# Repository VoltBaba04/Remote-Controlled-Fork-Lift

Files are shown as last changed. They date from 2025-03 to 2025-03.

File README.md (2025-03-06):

Remote-Controlled Forklift with Video Streaming

**Project Overview :** 
This project is a remote-controlled forklift system designed for industrial use, controlled using Arduino Nano with live video streaming via ESP32-CAM. The forklift is controlled remotely using two joysticks: one for 4WD vehicle movement and the other for forklift lift and angle control. The project uses NRF24L01 wireless modules for long-range communication between the transmitter and receiver. The ESP32-CAM module streams live video, allowing real-time monitoring of the forklift’s environment.

**System Architecture :** 
The system is divided into two main sections: the transmitter and the receiver.

**Transmitter:**
Arduino Nano: 
Processes inputs from joysticks.

**NRF24L01:**
Transmits the joystick control signals wirelessly.

**Two Joysticks:**
Joystick 1: Controls vehicle movement (forward, reverse, left, right).
Joystick 2: Controls forklift lifting and fork angle.

**Power Supply:**
Powered by USB or a regulated 5V power source.

**Receiver:**
Arduino Nano:
Receives commands and controls the motors.

**NRF24L01:**
Receives wireless signals from the transmitter.

**L298N Motor Drivers (2):**
One motor driver controls 4WD motors for vehicle movement.
The other motor driver controls the forklift lifting motor.

**ESP32-CAM:**
Streams live video for real-time monitoring of the forklift's surroundings.

**Li-ion Battery Packs:**
Two packs of 4 Li-ion cells (2500mAh each) connected in series and in parallel for sufficient voltage and current.

**Buck Converter:**
Steps down voltage from the battery pack for the Arduino and other components.

**Stop Switch:**
Prevents the forklift from over-extending when lifting.

**Hardware Components**

**Transmitter:**

**Arduino Nano:** 
Main controller for joystick input.

**NRF24L01 Module with External Antenna:** 
Wireless communication.

**Two Joysticks:**
For controlling the forklift.

**USB Power Supply:**
Or external 5V regulated supply.

**Receiver:**

**Arduino Nano:** 
Receives signals from the transmitter and controls the motors.

**NRF24L01 Module with External Antenna:**
Wireless communication.

**ESP32-CAM:**
Streams live video over Wi-Fi.

**L298N Motor Drivers (2):**
Motor Driver 1: 
Controls 4WD vehicle motors.

Motor Driver 2: 
Controls forklift lift motor.

Li-ion Batteries (8x 2500mAh):
Two packs connected in parallel and series (14.8V).

**Buck Converter:** 
To step down voltage for the Arduino Nano.

**Stop Switch:**
To control the upward motion of the forklift.

**Power Supply Setup**

Batteries: 
Two packs of 4 Li-ion batteries (2500mAh) in series, connected in parallel. Each battery provides 3.7V, so the total voltage is 14.8V.

Buck Converter:
Reduces the voltage from 14.8V to 5V for the Arduino Nano and NRF24L01.

**How to Set Up the Project**

**1. Transmitter Side Setup:**

**Hardware Connections:**

Connect two joysticks to the Arduino Nano:
Joystick 1 controls 4WD motors.
Joystick 2 controls forklift lifting and angle.
Connect the NRF24L01 module to the Arduino Nano.
Power the transmitter using USB or a regulated 5V power source.

**Upload Code:**
Write the code to read joystick inputs and send the 
data via NRF24L01.
Use the Arduino IDE to upload the transmitter code.

**2. Receiver Side Setup:**

**Hardware Connections:**

Connect the Arduino Nano to the NRF24L01 module.
Connect the ESP32-CAM module to stream live video over Wi-Fi.
Connect the L298N motor drivers to control the 4WD motors and forklift motor.
Connect the battery packs and buck converter to provide power to the receiver.
Add the stop switch to prevent the forklift from over-extending when lifting.

**Upload Code:**
Write the receiver code to handle motor control and video streaming.
Use the Arduino IDE to upload the receiver code.
Code and Software

**1. Transmitter Code:**
Reads inputs from the joysticks.
Sends control signals (for forklift movement and lifting) via NRF24L01.

**3. Receiver Code:**
Receives control signals via NRF24L01.
Controls the L298N motor drivers to move the forklift and operate the lift.
Streams live video using the ESP32-CAM module over Wi-Fi.

**5. Video Streaming Code (ESP32-CAM):**
The ESP32-CAM streams live video using its onboard camera module.
The video feed is accessible via a local IP address over the same Wi-Fi network.
Testing and Results

**1. Wireless Communication Range:**
The system maintains reliable communication within a range of approximately 200 meters using the NRF24L01 module with an external antenna.

**3. Video Streaming:**
The ESP32-CAM provides a live video feed with low latency, allowing the operator to view the forklift’s surroundings in real-time.

**5. Motor Control:**
The L298N motor drivers efficiently control the 4WD motors and the forklift lift motor, providing smooth operation.
Challenges and Solutions

**1. Power Management:**
Ensuring stable power supply for both the high-power motors and the low-power Arduino Nano and communication modules was a challenge.
The use of a buck converter to step down voltage ensured reliable operation without power fluctuations.

**3. Communication Range:**
The NRF24L01 module with an external antenna was chosen to ensure a reliable communication range of up to 200 meters, which is suitable for most industrial applications.
Future Improvements

**Autonomous Features:** Adding sensors for collision detection or autonomous movement.

**Improved Video Quality:** Upgrading to a higher resolution camera for clearer video feeds.

**Extended Range:** Using a more powerful communication module like LoRa for extended range operation.

**Battery Management System (BMS):** Integrating a BMS to protect the Li-ion batteries from overcharging and over-discharging.
Conclusion

This project successfully developed a remote-controlled forklift with live video streaming. It allows the operator to control the forklift’s movement and lifting mechanism remotely while viewing the surroundings via a live video stream. The system uses NRF24L01 for long-range wireless communication and ESP32-CAM for video streaming, making it a versatile and practical solution for industrial applications.

**References**
NRF24L01 Datasheet
ESP32-CAM Documentation
L298N Motor Driver Datasheet
Arduino Nano Pinout and Specifications

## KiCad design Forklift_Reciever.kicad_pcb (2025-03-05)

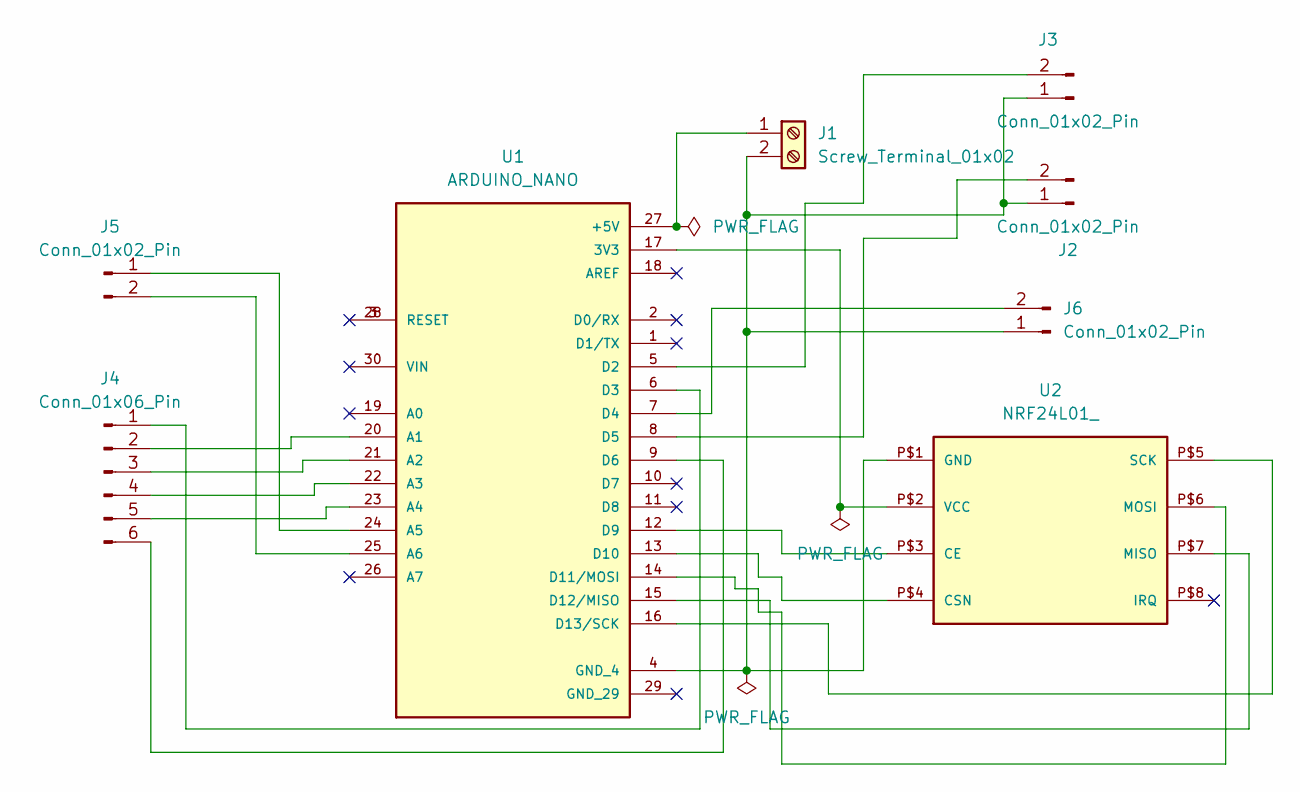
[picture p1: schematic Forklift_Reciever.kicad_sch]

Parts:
J1: Screw_Terminal_01x02; TerminalBlock_Phoenix_MKDS-1,5-2-5.08_1x02_P5.08mm_Horizont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
J2, J3, J5, J6: Conn_01x02_Pin; PinHeader_1x02_P2.54mm_Vertical
J4: Conn_01x06_Pin; PinHeader_1x06_P2.54mm_Vertical
U1: ARDUINO_NANO; MODULE_ARDUINO_NANO; PARTREV 30/06/2021
U2: NRF24L01_; NRF24L01-PCB-AERIAL

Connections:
unnamed: J1.1, U1.27 (+5V)
unnamed: J1.2, J2.1, J3.1, J6.1, U1.4 (GND_4), U2.P$1 (GND)
unnamed: J2.2, U1.8 (D5)
unnamed: J3.2, U1.5 (D2)
unnamed: J4.1, U1.6 (D3)
unnamed: J4.2, U1.20 (A1)
unnamed: J4.3, U1.21 (A2)
unnamed: J4.4, U1.22 (A3)
unnamed: J4.5, U1.23 (A4)
unnamed: J4.6, U1.9 (D6)
unnamed: J5.1, U1.24 (A5)
unnamed: J5.2, U1.25 (A6)
unnamed: J6.2, U1.7 (D4)
unnamed: U1.17 (3V3), U2.P$2 (VCC)
unnamed: U1.12 (D9), U2.P$3 (CE)
unnamed: U1.13 (D10), U2.P$4 (CSN)
unnamed: U1.14 (D11/MOSI), U2.P$6 (MOSI)
unnamed: U1.15 (D12/MISO), U2.P$7 (MISO)
unnamed: U1.16 (D13/SCK), U2.P$5 (SCK)

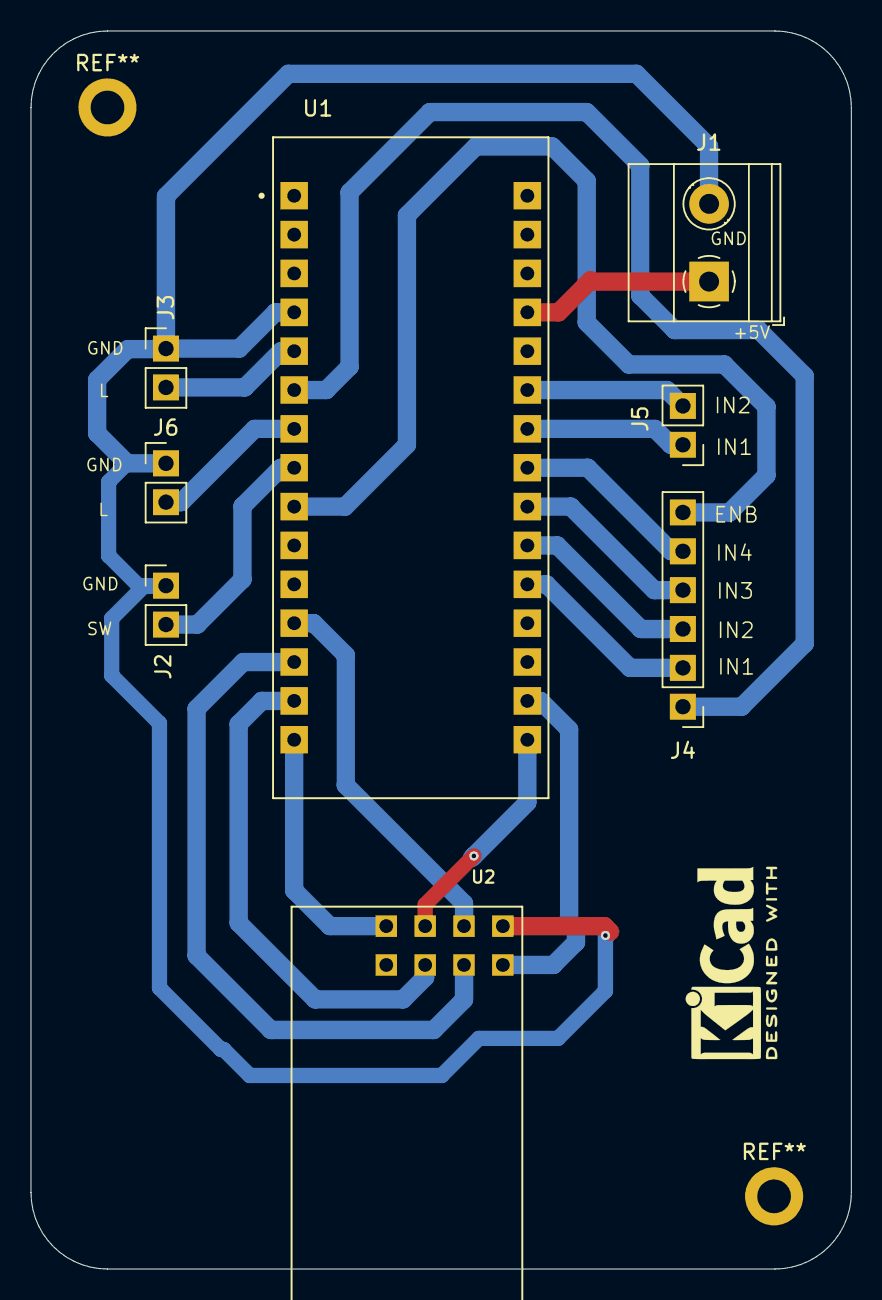
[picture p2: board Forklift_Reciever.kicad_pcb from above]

Board: 2 copper layers, 53.6 x 80.9 mm, 8 parts (0 on the bottom side), 19 nets.

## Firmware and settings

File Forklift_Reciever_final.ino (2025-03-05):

#include <SPI.h>
#include <RF24.h>

// Define pins for L298N motor drivers
const int motor1Pin1 = A1;  // Left Motor Forward (IN1) connected to A1
const int motor1Pin2 = A2;  // Left Motor Reverse (IN2) connected to A2
const int motor2Pin1 = A3;  // Right Motor Forward (IN3) connected to A3
const int motor2Pin2 = A4;  // Right Motor Reverse (IN4) connected to A4
const int enablePin1 = 3;   // Left Motor Enable (ENA) connected to digital pin 3 (PWM control)
const int enablePin2 = 6;   // Right Motor Enable (ENB) connected to digital pin 6 (PWM control)

const int motor3Pin1 = A5;  // Lifting Motor Forward control pin connected to A5
const int motor3Pin2 = A6;  // Lifting Motor Reverse control pin connected to A6

const int stopSwitchPin = 7; // Stop switch for the fork connected to digital pin 7 (input)
const int ledPin1 = 2;       // Headlight LED1 control pin connected to digital pin 2
const int ledPin2 = 5;       // Headlight LED2 control pin connected to digital pin 5

// Define RF24 module pins
const int cePin = 9;  // CE pin for the NRF24L01 module connected to digital pin 9
const int csnPin = 10; // CSN pin for the NRF24L01 module connected to digital pin 10

// Create an RF24 object using CE and CSN pins
RF24 radio(cePin, csnPin);

// Define the address of the receiving node
const uint64_t pipe = 0xE8E8F0F0E1LL;  // This is the unique address for communication between the transmitter and receiver

// Declare variables for headlights toggle
bool headlightsState = false;
bool previousHeadlightsState = false;

// Function to set PWM and direction for the motors
void setMotorPWM(int enablePin, int motorPin1, int motorPin2, int speed) {
  if (speed > 0) {
    analogWrite(enablePin, speed);
    digitalWrite(motorPin1, HIGH);
    digitalWrite(motorPin2, LOW);
  } else if (speed < 0) {
    analogWrite(enablePin, -speed);
    digitalWrite(motorPin1, LOW);
    digitalWrite(motorPin2, HIGH);
  } else {
    analogWrite(enablePin, 0);
    digitalWrite(motorPin1, LOW);
    digitalWrite(motorPin2, LOW);
  }
}

void setup() {
  // Initialize serial communication for debugging
  Serial.begin(9600);

  // Initialize RF24 module
  if (!radio.begin()) {  // Begin communication with the NRF24L01 module
    Serial.println("RF24 initialization failed!");  // Print an error if the radio fails to initialize
    while (1); // Halt the program
  }
  radio.openReadingPipe(1, pipe);  // Open a reading pipe at address 'pipe'
  radio.setPALevel(RF24_PA_HIGH);  // Set the power amplifier level to high for better performance
  radio.setDataRate(RF24_1MBPS);  // Set data rate to 1Mbps for a good balance of speed and range
  radio.startListening();  // Start listening for incoming data
  Serial.println("RF24 initialized successfully.");  // Print confirmation if initialization is successful

  // Set motor driver pins as outputs
  pinMode(motor1Pin1, OUTPUT);  // Left motor forward pin as output
  pinMode(motor1Pin2, OUTPUT);  // Left motor reverse pin as output
  pinMode(motor2Pin1, OUTPUT);  // Right motor forward pin as output
  pinMode(motor2Pin2, OUTPUT);  // Right motor reverse pin as output
  pinMode(enablePin1, OUTPUT);  // Enable pin for left motor as output (PWM control)
  pinMode(enablePin2, OUTPUT);  // Enable pin for right motor as output (PWM control)
  pinMode(motor3Pin1, OUTPUT);  // Lifting motor forward pin as output
  pinMode(motor3Pin2, OUTPUT);  // Lifting motor reverse pin as output
  pinMode(stopSwitchPin, INPUT_PULLUP);  // Stop switch pin set as input with internal pull-up resistor
  pinMode(ledPin1, OUTPUT);  // LED1 pin as output
  pinMode(ledPin2, OUTPUT);  // LED2 pin as output
}

void loop() {
  // Struct to hold received data
  struct Data {
    int vehicleSpeedX;  // Speed for vehicle movement on the X-axis (left-right)
    int vehicleSpeedY;  // Speed for vehicle movement on the Y-axis (forward-backward)
    int forkSpeed;      // Speed for controlling the fork up and down
    bool headlightsOn;  // Boolean to control headlights (this indicates if the button is pressed)
  };
  Data receivedData;  // Create an instance of the struct to store received data

  // Check if data is available from the transmitter
  if (radio.available()) {
    radio.read(&receivedData, sizeof(receivedData));  // Read the data into 'receivedData'

    Serial.print("Received Data - Vehicle Speed X: ");
    Serial.print(receivedData.vehicleSpeedX);
    Serial.print(" | Vehicle Speed Y: ");
    Serial.print(receivedData.vehicleSpeedY);
    Serial.print(" | Fork Speed: ");
    Serial.print(receivedData.forkSpeed);
    Serial.print(" | Headlights On: ");
    Serial.println(receivedData.headlightsOn ? "True" : "False");

    int leftMotorSpeed = receivedData.vehicleSpeedY + receivedData.vehicleSpeedX;
    int rightMotorSpeed = receivedData.vehicleSpeedY - receivedData.vehicleSpeedX;

    // Ensure motor speeds are within the valid range (0-255 for PWM)
    leftMotorSpeed = constrain(leftMotorSpeed, -255, 255);
    rightMotorSpeed = constrain(rightMotorSpeed, -255, 255);

    // Debug motor speeds
    Serial.print("Left Motor Speed: ");
    Serial.print(leftMotorSpeed);
    Serial.print(" | Right Motor Speed: ");
    Serial.println(rightMotorSpeed);

    // Control vehicle motors for tank-like movement with PWM using the setMotorPWM function
    setMotorPWM(enablePin1, motor1Pin1, motor1Pin2, leftMotorSpeed);
    setMotorPWM(enablePin2, motor2Pin1, motor2Pin2, rightMotorSpeed);

    // Control lifting motor for fork movement with the second joystick's Y-axis (no PWM)
    if (receivedData.forkSpeed > 0) { 
      // Lift fork up
      digitalWrite(motor3Pin1, HIGH); 
      digitalWrite(motor3Pin2, LOW); 
      Serial.println("Lifting fork up");
    } else if (receivedData.forkSpeed < 0) { 
      // Lower fork
      digitalWrite(motor3Pin1, LOW); 
      digitalWrite(motor3Pin2, HIGH); 
      Serial.println("Lowering fork");
    } else { 
      // Hold fork position (no movement)
      digitalWrite(motor3Pin1, LOW);
      digitalWrite(motor3Pin2, LOW);
      Serial.println("Holding fork position");
    }

    // Toggle headlights on button press
    if (receivedData.headlightsOn && !previousHeadlightsState) {  // Detect a rising edge (button press)
      headlightsState = !headlightsState;  // Toggle the state of the headlights
    }
    previousHeadlightsState = receivedData.headlightsOn;  // Update the previous button state

    // Set the headlights based on the toggled state
    if (headlightsState) {
      digitalWrite(ledPin1, HIGH);  // Turn on LED1 (headlight)
      digitalWrite(ledPin2, HIGH);  // Turn on LED2 (headlight)
    } else {
      digitalWrite(ledPin1, LOW);   // Turn off LED1
      digitalWrite(ledPin2, LOW);   // Turn off LED2
    }

    // Print all data to the serial monitor for debugging
    Serial.print("Vehicle Speed X: ");
    Serial.print(receivedData.vehicleSpeedX);
    Serial.print(" | Vehicle Speed Y: ");
    Serial.print(receivedData.vehicleSpeedY);
    Serial.print(" | Fork Speed: ");
    Serial.print(receivedData.forkSpeed);
    Serial.print(" | Headlights On: ");
    Serial.println(headlightsState ? "True" : "False");
  }
}
